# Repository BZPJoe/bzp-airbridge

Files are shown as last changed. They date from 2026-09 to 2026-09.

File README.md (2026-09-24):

# BZP Airbridge

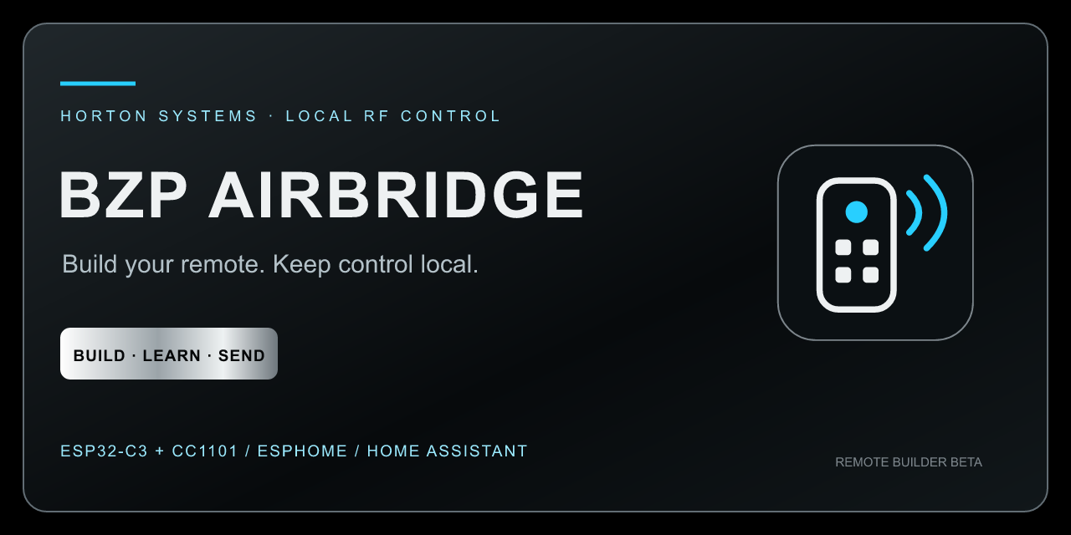
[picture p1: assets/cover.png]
BZP Airbridge — build your remote, keep control local


**Build your remote. Learn its buttons. Keep control local.**

An ESP32-C3 + CC1101 RF bridge with an offline settings page, visual Remote Builder, encrypted ESPHome connectivity, and optional Home Assistant/HomeKit fan control.

**v0.2.0 beta.** Airbar power replay has been confirmed on the project hardware. A captured signal is not proof of appliance compatibility. This is not a universal remote or rolling-code bypass.

## Features
 
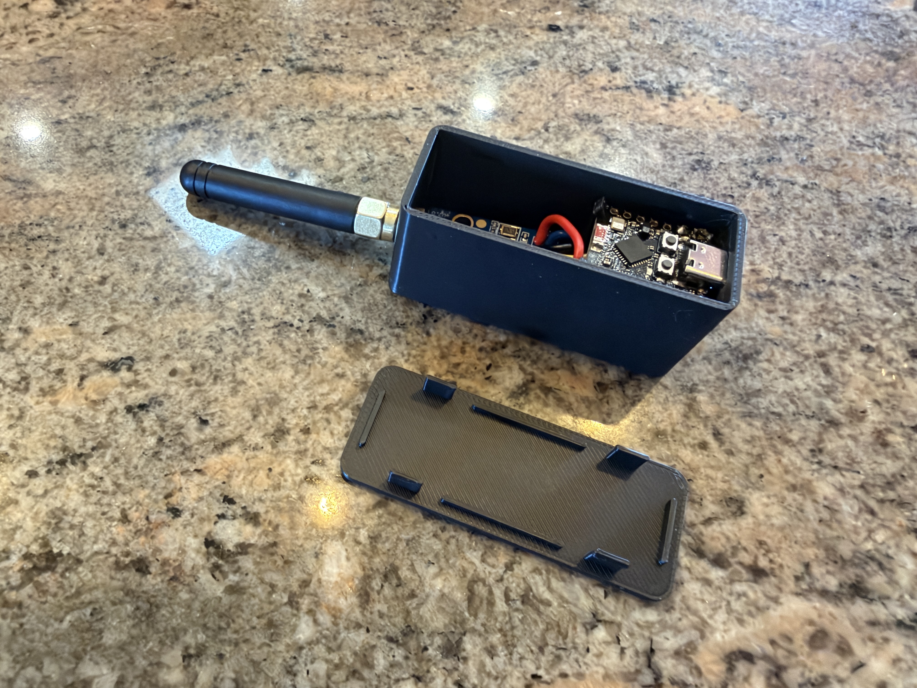
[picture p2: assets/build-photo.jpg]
BZP Airbridge assembled in its printed case, with the removable lid alongside


The actual project build: ESP32-C3 and CC1101 installed in the printed enclosure.

**Print this case:** [Download the case and print profile on MakerWorld](https://makerworld.com/en/models/3271985-bzp-airbridge-esp32-c3-cc1101-controller-case#profileId-3710223).

- Four custom remotes sharing eight custom button slots.
- Name, icon, and position editing before learning individual buttons.
- Animated 20-second listening countdown and explicit save/discard.
- Private JSON backup/import with schema and pulse validation.
- Stable Home Assistant custom-button entities.
- API-key finding aid for locating the existing ESPHome encryption key during Home Assistant setup; the key remains private and is never part of the public repository.
- Home Assistant keeps the last known fan state across Airbridge power loss and reconnects. The settings page provides **Sync fan state** (Off/Low/Medium/High), with the current Home Assistant estimate shown alongside it.
- Existing Vornado power/speed controls and stored captures preserved.
- 2.4 GHz Wi-Fi configuration with rollback, remote reboot, and password-protected ESPHome OTA.
- Horton Systems chrome/cyan styling; all page assets stored on-device.

**Update delivery:** Auto updates and Check for updates remain staged controls. They do not download GitHub releases in this beta. ESPHome OTA works separately.

## Start here

1. [Wire the hardware](docs/WIRING.md) with USB disconnected.
2. [Build and flash](docs/SETUP.md) using your own private credentials.
3. Open http://bzp-airbridge.local or your device’s local IP.
4. [Build and learn remotes](docs/REMOTE-BUILDER.md).
5. [Add Home Assistant and Apple Home](docs/HOME-ASSISTANT.md).

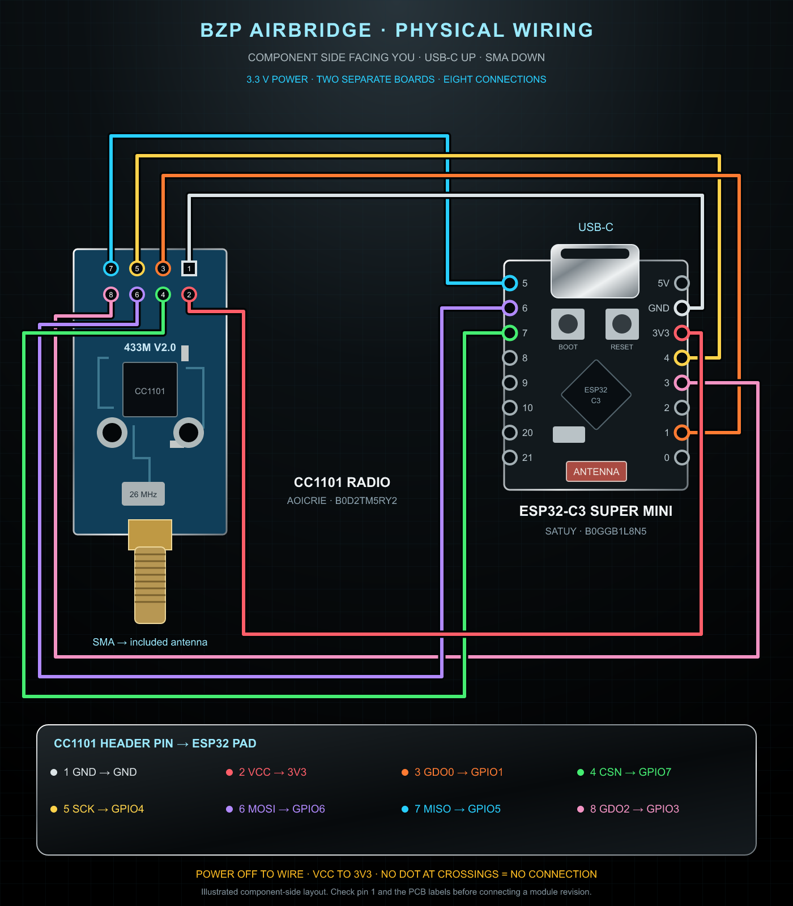
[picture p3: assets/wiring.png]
Physical boards and eight color-coded connections


## Compatibility

Project hardware: ESP32-C3 Super Mini (ASIN B0GGB1L8N5) and AOICRIE CC1101/SMA 433 MHz radio (ASIN B0D2TM5RY2). Board revisions differ: follow signal names and check pin 1.

**Get the parts:** [Below Zero Productions — Gear We Use & Recommend](https://www.belowz.com/gear/). This page contains Amazon affiliate links. As an Amazon Associate I earn from qualifying purchases.

Shipped profile: **433.937 MHz ASK/OOK**, eight-repeat playback. All custom remotes share this profile. Custom capacity: 16–256 alternating pulses, 50–30,000 µs each, 3–500 ms total. Protected legacy slots retain their 512-pulse format. No infrared, Bluetooth, rolling-code, automatic decoding, arbitrary FSK, or multi-frequency support is claimed. Operate only authorized devices and obey local RF rules.

## Home Assistant

The original three buttons retain their names. Eight additional entities are named **Custom button 1–8**. Their identities stay stable when you rename/reorder layout buttons; rename them separately in Home Assistant if desired. Empty slots refuse transmission.

The optional [fan package](examples/home-assistant/bzp_airbridge.yaml) wraps the Airbar controls as a three-speed fan. Its state is estimated, not physical feedback. Its dedicated HomeKit Bridge exports only `fan.bzp_airbridge` as one fan accessory; the Home Assistant bridge service page may itself show no entities. If a bridge was reset/unpaired, remove only its stale BZP Airbridge entry from Apple Home and pair again using the current Home Assistant notice. See [Home Assistant and Apple Home setup](docs/HOME-ASSISTANT.md). Custom remotes do not automatically become fans/lights/covers.

## Development

```sh
python3 -m venv .venv
. .venv/bin/activate
pip install -r requirements.txt
cp firmware/secrets.example.yaml firmware/secrets.yaml
# Replace example credentials before flashing.
python tools/build_ui.py
c++ -std=c++17 tests/test_pulses.cpp -o /tmp/airbridge-pulses && /tmp/airbridge-pulses
c++ -std=c++17 tests/test_builder.cpp -o /tmp/airbridge-builder && /tmp/airbridge-builder
node tests/test_builder.js
esphome compile firmware/airbridge.yaml
```

[Architecture](docs/ARCHITECTURE.md) · [Validation](docs/VALIDATION.md) · [Brand kit](docs/BRAND.md) · [Changelog](CHANGELOG.md) · [Contributing](CONTRIBUTING.md) · [Security](SECURITY.md)

[Settings preview](docs/settings-preview.html) works when served locally and cannot control hardware. Download the [owner-supplied case base and top](hardware/enclosure/user-supplied/README.md). The [earlier generated enclosure](hardware/enclosure/PRINT_AND_ASSEMBLY.md) is retained as a prototype reference; its measurements do not apply to the owner-supplied parts.

[Full settings screenshot](assets/remote-builder-preview.png) · [390 px layout preview](docs/mobile-preview.html)

[MakerWorld description](docs/MAKERWORLD.md) · [Case-parts render](assets/makerworld/case-parts-render.png) · [Software overview](assets/makerworld/software-overview.png)

## Privacy and license

Never publish personal secrets, compiled firmware, raw radio logs, or private remote backups. RF backups can control your devices even without Wi-Fi credentials. Public releases contain source only.

Original code/artwork: [MIT](LICENSE). Horton Systems branding remains its owner's property. See [third-party notices](THIRD_PARTY_NOTICES.md). Independent project, unaffiliated with Vornado, Espressif, Texas Instruments, Apple, or Home Assistant.

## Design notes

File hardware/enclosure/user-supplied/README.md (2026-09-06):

# User-supplied case — September 6, 2026

These are the project owner's supplied case parts, preserved byte-for-byte. Use these files for the current case rather than the earlier generated prototype in the parent folder.

- [Base](Vornado%20Fan%20Controller%20Case.stl): 15,248 triangles; bounding dimensions 60 × 24 × 25.786 model units.
- [Top](Vornado%20Fan%20Controller%20Case%20Top.stl): 4,106 triangles; bounding dimensions 60.7 × 24.7 × 6.986 model units.

STL does not encode units; confirm millimeters and orientation in your slicer. Binary STL structure was checked. No geometry, mounting features, or print supports were added. These files have not been physically fit-tested by this release process. The earlier prototype's assembly dimensions and validation report do not describe these parts.

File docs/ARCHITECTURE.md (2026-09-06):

# Architecture

ESPHome 2026.8.2 supplies Wi-Fi, encrypted native API, OTA, CC1101 state switching, and RMT pulse I/O. Airbridge adds the local UI, validated capture storage, and explicit replay controls.

## Protected Vornado controls

The original three globals retain their identities and 512-pulse capacity. Existing captures survive the builder upgrade. They use ESPHome preferences with a one-minute flash interval; allow 65 seconds after saving before disconnecting power.

## Custom Remote Builder

Four remote names share eight stable button slots. Each button has a label, icon, position, remote assignment, and at most 256 signed pulse durations. The 4,552-byte versioned store is committed as a separate NVS blob (bzp_builder/store_v2). Custom saves acknowledge only after commit; failed imports preserve the prior store. A pending candidate remains separate until Save; Cancel preserves the previously saved command.

GET /airbridge/builder returns layout, status, revision, and private captures. POST accepts raw JSON with Content-Type: application/json and X-Airbridge-Request: builder. Payloads are bounded to 26,000 bytes. Operations: replace, learn, save, cancel, send. HTTP 200 with Accepted means queued, not completed: clients poll until revision changes, then inspect error. Never automatically repeat an uncertain send request.

Input checks cover schema/profile, slot counts, name lengths, integer bounds, pulse count/polarity/duration, and active remote assignments. The device defers mutations to its main loop. Native HTTP body delivery is chunked; URL-encoded form handling is deliberately not used for layouts.

## Radio and integrations

All slots share 433.937 MHz ASK/OOK, eight repeats, zero added gap. Explicit valid sends automatically enable transmission. Learning, pending custom candidates, overlapping sends, and invalid/empty frames block replay. The radio returns to receive after transmission. These are emission checks, not appliance feedback.

Home Assistant sees the original three buttons plus eight stable Custom button entities. A separate optional three-speed fan wrapper maintains an estimate and exposes only that fan through HomeKit. Physical remote use requires resynchronization.

## Security boundary

The no-login HTTP page is for a trusted isolated LAN only. The custom request header is a cross-origin browser defense, not authentication. RF backups contain usable control data. API encryption and OTA passwords do not encrypt the web page. Keep the device off the public Internet and do not publish private backups or deployment binaries.

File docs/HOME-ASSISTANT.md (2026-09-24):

# Home Assistant and Apple Home

## Add the ESPHome device to Home Assistant

Add the Airbridge through Home Assistant's ESPHome integration using its API encryption key. The Airbridge settings page now includes an API-key finding aid to help locate the existing key needed for setup. Treat the discovered key as a credential: use it only for the local ESPHome connection, and never paste it into public issues, screenshots, or GitHub files. The key finder does not replace the ESPHome pairing flow.

Native custom button entities 1–8 keep stable identities; their labels in Remote Builder do not rename Home Assistant entities. Empty slots cannot transmit. Explicit commands automatically enable transmission; learning and overlapping sends still block playback.

## Optional fan wrapper

The [example package](../examples/home-assistant/bzp_airbridge.yaml) is the project's three-speed Airbar wrapper. It is not a universal fan profile. Verify the number of speeds, non-wrapping speed-down behavior, and all three learned commands before using it. Adjust entity IDs to match your installation.

1. Enable packages under `homeassistant: packages: !include_dir_named packages` in your existing configuration, merging rather than duplicating that section.
2. Place the example in `packages/bzp_airbridge.yaml`.
3. Check configuration, then restart Home Assistant.
4. In the Airbridge settings page, use **Sync fan state** to select the fan's actual Off/Low/Medium/High state, then press **Sync fan state**. The Home Assistant estimate on the page confirms the change. The Home Assistant resync selector is also available. A first installation starts Unsynced until this is done.

Power-on from Off normalizes to Low with two speed-down commands before stepping to the target. This assumes a three-speed fan that stops at Low rather than cycling. Every command is serialized. A completed RF replay means the bridge emitted the signal—not that the appliance received it. Fan state is estimated, not physical feedback. After using a physical remote or changing power externally, resync the estimate.

## Power loss and manual sync

Starting with 0.2.2-beta.1, the package retains its last known fan estimate through an Airbridge power loss, Wi-Fi disconnect, or Home Assistant restart. HomeKit can show No Response while the bridge is actually disconnected; control returns automatically with the saved estimate after it reconnects. It does not transmit a command to force the physical fan into that state.

The estimate is stored in Home Assistant's restoring input-select helper. Changes to the physical fan while the bridge is offline can make it inaccurate. Correct it under **Sync fan state** in the device settings page: choose Off, Low, Medium, or High and press the sync button. This updates Home Assistant and HomeKit without transmitting RF. It also stops any pending fan-control sequence so it cannot overwrite your correction.

Upgrade both the firmware and the example Home Assistant package. For an existing package installation, validate configuration and reload automations after replacing the package. Remove the old `bzp_airbridge_observer_disconnect` automation if you merged the update manually; leaving it active still clears state on disconnect. Keep the existing helper and entity IDs so their stored state and Apple Home identity are preserved.

Received commands and completed web-page replays update the estimate when observed in sequence. Reconnect snapshots and sequence gaps retain the prior estimate instead of guessing what happened while offline. Passive handheld recognition depends on the radio receiving the remote reliably; it is not physical fan feedback. Failed/interrupted control sequences may still require manual sync.

## Publish the fan to Apple Home

Home Assistant and Apple Home are two separate steps. The ESPHome device appearing in Home Assistant does not automatically add an accessory to Apple Home.

The dedicated HomeKit Bridge section in the example exports **only `fan.bzp_airbridge`**, named **BZP Airbridge**, on port **21268**. When paired, Apple Home should show a fan accessory with on/off and three-speed control. Do not add the power switch and speed selector separately; the fan entity is the combined accessory.

1. Confirm `fan.bzp_airbridge` is available (not `unavailable`). On first setup, or if the estimate is Unsynced after an interrupted command, use **Sync fan state** to enter the fan's actual state. Ordinary reconnects preserve the estimate.
2. Check Home Assistant configuration, then restart Home Assistant or run the HomeKit reload action to apply YAML changes.
3. In Home Assistant, open **Settings → Devices & services → HomeKit Bridge**. Find **BZP Airbridge** and its pairing card/code in Notifications.
4. In Apple Home, choose **Add Accessory**, then scan the QR code or use **More Options / Don't Have a Code?** and enter the current code. Keep the iPhone and Home Assistant on the same local network so discovery can work.
5. Look for the **BZP Airbridge** fan accessory in Apple Home. The Home Assistant HomeKit *service device* page may say “This device has no entities”; that page represents the bridge service and is not the accessory list.

### If the bridge is already in Apple Home but has no fan

Confirm `fan.bzp_airbridge` is available and the HomeKit filter includes that entity. If the bridge was forcefully unpaired or reset in Home Assistant, Apple Home may still show its old saved bridge entry even though it no longer matches the active pairing.

Remove **only the stale BZP Airbridge bridge** from Apple Home, then add it again using the current BZP Airbridge pairing notice in Home Assistant Notifications. Unpairing applies to this HomeKit bridge; it does not affect other Home Assistant HomeKit bridges. After re-pairing, check the Home app's bridge/accessory details and its room for the fan tile.

If the bridge cannot be discovered, verify both devices are on the same LAN and the router allows local multicast/mDNS discovery; guest Wi-Fi, client isolation, VLANs, or multicast filtering can prevent discovery. Do not delete unrelated HomeKit bridges.

Home Assistant uses entity IDs as HomeKit accessory identity, so keep `fan.bzp_airbridge` stable if you want to preserve its Home app settings. HomeKit changes may take a moment to appear after a reload.

## Custom commands

Custom buttons can be used in automations with `button.press`. They do not automatically map to fan percentages or Apple Home accessories. Build a separate suitable wrapper for each appliance; never apply this fan state model to a different remote without testing.

Keep API keys, Wi-Fi credentials, pairing codes, and household configuration private. Do not put live setup codes or personal network details in this repository.

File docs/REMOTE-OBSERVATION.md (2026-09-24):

# Physical remote observation (0.2.1 beta)

The receiver now compares incoming frames with the three saved fan commands outside learning mode. Matching uses the full signed pulse sequence with 25% + 80 microseconds tolerance, excluding the trailing receiver idle gap. Ambiguous matches are rejected. Repeated copies of the same command within 350 ms of the preceding copy count once. Holding a button is treated as one press until a 350 ms gap; rapid same-button presses may merge. This conservative behavior needs validation with the actual remote.

The diagnostic Observed command sensor reports sequence:source:slot. Source is rx (physical remote) or tx (completed bridge replay); slots 0/1/2 are power/up/down. Starting in 0.2.2, source sync means an explicit settings-page correction; values 0/1/2/3 mean Off/Low/Medium/High. Sync never transmits RF. Background listening never retransmits. Own transmissions and the first 350 ms afterward are excluded. Commands during learning, pending capture review, transmission or radio/Wi-Fi downtime can be missed.

Home Assistant's observer automation updates the existing estimate. The fan-control script already accounts for its own sends, so the automation ignores those tx reports. Direct web/button sends are counted. A physical command during a fan-control sequence stops that sequence and marks the estimate Unsynced. Since 0.2.2, disconnects and sequence gaps retain the last known estimate; reconnect snapshots are ignored. The settings-page **Sync fan state** control and the Home Assistant resync selector can correct an inaccurate estimate.

This is command observation, not appliance feedback. The three-speed model assumes bounded speed steps, speed commands do nothing while off, and power-on resumes the remembered speed. If your fan behaves differently, change the model rather than treating this estimate as fact. Fan-panel changes and missed RF packets remain invisible. Start by setting the resync selector to the actual state, then test power, individual speed presses, rapid presses and held buttons with the physical fan in view.

Recognition has synthetic tests; physical RF acceptance still requires a real remote test after installation. Custom Remote Builder buttons are not assigned fan-state semantics.

## Receive-path diagnostics

`Inspect remote reception` opens a 60-second diagnostic window. It logs saved
frames, raw callback counts and up to six received samples, without changing
saved captures. Keep diagnostic logs private: learned RF codes should not be
published with the project.

`Test receive line` is specific to this project's GDO2-to-GPIO3 wiring. It
temporarily drives GDO2 low/high twelve times, reads GPIO3, then restores the
original radio output configuration. It does not enter transmit mode. Learning
and observation are suppressed during the test. Twelve successful low and high
reads plus a receiver callback verify the digital receive path, not RF reception.

Raw mode disables packet synchronization. In the dual-pin configuration GDO0
is high-impedance while receiving, since the ESP32 RMT transmit pin remains an
output; GDO2 supplies received data independently. GDO0 is automatically the
radio's data input in asynchronous transmit mode.

The receiver bandwidth setter also applies the matching analog settings from
[TI DN022 section 3.2](https://www.ti.com/lit/an/swra215e/swra215e.pdf).
At 203.125 kHz these are FREND1=B6, TEST2=81, TEST1=35 and FIFOTHR bit 6=1.
The OOK AGC starting point is 03/00/91, with frequency compensation disabled.
These are documented starting settings, not a substitute for over-the-air
acceptance testing at the installation location. The timed reception diagnostic
also reports min/max RSSI and sampled GPIO3 levels once per second.

`Scan remote reception` is an 18-second receive-only diagnostic: nine two-second
steps from 433.137 to 434.737 MHz using a 650 kHz receive bandwidth and 355 kHz IF.
Record an untouched-remote baseline first, then repeat with the physical remote.
The scan blocks replay and learning, does not update the fan estimate, and restores
this firmware's normal 433.937 MHz / 203 kHz / 153 kHz IF profile automatically.
No scan setting or received sample is saved to flash. Restarting also restores
the normal configured profile. Background RF energy is not proof of remote reception.
# Temporary USB reception comparisons

These diagnostics are experimental, not a confirmed passive-reception fix.
`Original reception test` restores the published learning-era modem and analog
register values for five minutes, while keeping the shared TX-connected GDO0
high impedance to avoid output contention. Frequency and saved commands are
preserved. All incoming callbacks are counted before the application's validity
checks or observer matching. The normal settings are restored automatically.
This is a controlled comparison, not an exact rollback of the entire firmware.
`USB quiet reception test` records five seconds with Wi-Fi enabled, disables
Wi-Fi for 30 seconds while USB logging continues, then reenables Wi-Fi.
`Reference reception test` snapshots the normal radio configuration, reads
the chip's reset defaults and applies an OOK 270 kHz receive profile adapted
from the [Flipper CC1101 configurations](https://github.com/flipperdevices/flipperzero-firmware/blob/dev/lib/subghz/devices/cc1101_configs.c).
It retains the configured frequency and uses GDO2 for reception. After 90 seconds
it automatically restores the normal configuration. Both tests block replay and
learning, leave saved captures intact, and do not update estimated fan state.
A reboot also restores the normal configured profile. Verify actual fan state
before manually resynchronizing Home Assistant after testing.

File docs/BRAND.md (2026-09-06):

# Brand kit

**BZP Airbridge** · Build your remote. Keep control local.

Horton Systems header branding, black/steel panels, chrome buttons, and cyan accents match the owner's UniFi Sentinel style. The new geometric mark combines a remote with radio arcs, not generated fan blades.

| Token | Color |
|---|---|
| Black / panel | #000000 / #0B1013 |
| Steel / chrome | #7C858B / #EEF1F2 |
| Cyan / pale cyan | #28CFFF / #9BEAFF |
| Green / amber | #45ED72 / #FFBD22 |

Editable assets: icon.svg, wordmark.svg, cover.svg, wiring.svg. PNG counterparts are portable exports. Cover dimensions: 1280×640. Preserve clear space and proportions.

python tools/build_ui.py embeds the current assets/UI. python tools/render_assets.py requires resvg-py and produces PNGs. Horton Systems branding remains its owner's property.

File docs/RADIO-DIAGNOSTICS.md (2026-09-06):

# Radio diagnostics

The local `cc1101` component is based on ESPHome 2026.8.2's component, with read-only register diagnostics added to its public interface. Upstream: https://github.com/esphome/esphome/tree/2026.8.2/esphome/components/cc1101 (ESPHome C++ runtime, GPLv3; see the included upstream license).

`Read radio diagnostics` is a diagnostic button exposed through ESPHome. Pressing it reads PARTNUM, VERSION, MARCSTATE, PKTCTRL0 and FSCAL1 and logs the saved Power pulse sequence without altering it. Run it when the bridge is idle.

Replay now enters TX before handing pulses to the transmitter. If MARCSTATE is not TX (`0x13`), it aborts replay and reports an error. After pulse completion, it checks RX (`0x0D`). Successful state transitions and pulse completion do not prove RF reception by the fan.

Stored frame IDs and serialization are unchanged. Raw frame timings can identify a remote's command; keep diagnostic logs private.

Live diagnostic finding: the saved Power frame contains 50 signed durations and ends in a -12000 us receiver idle period. The former extra 12 ms repeat wait doubled this separation. Replay now preserves the captured trailing gap and adds no extra repeat delay. Hardware fan response remains the final acceptance test.

Further live readback: PA=00,40; FREND0=11; MDMCFG2=32; IOCFG0=0D; FREQ=10B09C. GPIO1 output selection is 0x33 (RMT source 51), with GPIO1 output enabled. This rules out a zeroed OOK power table and a detached RMT route at the time of reading, but does not measure radiated RF.

The AIRBAR FCC grant lists 433.937 MHz: https://fccid.io/WOT-AIRBAR . The radio remains at that carrier. An eight-repeat playback trial replaces the former three repeats to test the longer burst envelope observed from the original remote. This is experimental until the user confirms fan response; the stored frame is unchanged.

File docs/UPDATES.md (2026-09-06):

# Staged software updates

The settings page and Home Assistant expose:

- Auto updates: a persistent preference, off by default.
- Check for updates: a manual action.
- Update status and Firmware version: device-reported text.

There is no release URL, GitHub request, download, or automatic installation in
this build. The manual check reports that a release source is not configured.
When the preference is enabled, a six-hour timer calls that same staged check.
It cannot claim the firmware is up to date without an actual release check.

When GitHub releases are ready, connect the shared check_updates hook to the
release mechanism, including version comparison, artifact validation, installation
status, failure handling, and rollback testing. Honor the stored Auto updates
preference for automatic installation. Manual checks must not automatically install
when that preference is off.

Existing password-protected ESPHome OTA remains available for development.
Before publishing public update binaries, establish a provisioning scheme that
keeps each user's Wi-Fi/API/OTA credentials out of the release artifact.

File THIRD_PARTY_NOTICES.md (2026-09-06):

# Third-party notices

- ESPHome 2026.8.2: https://github.com/esphome/esphome/tree/2026.8.2 — C++ runtime GPLv3; Python and other portions MIT. Vendored firmware/components/cc1101 comes from that release with local diagnostic additions and retains its upstream license. See licenses/ESPHome-LICENSE.txt. The root MIT license does not replace upstream licensing; combined firmware is subject to upstream runtime terms.
- Horton Systems logo belongs to its owner, included with project-owner authorization; not relicensed by MIT.
- Settings styling follows the owner's UniFi Sentinel project: https://github.com/BZPJoe/unifi-sentinel .
- Platform/manufacturer names identify compatibility targets, not endorsement.
- Original Airbridge SVG artwork is licensed with the project. Board drawings are illustrations, not certified mechanical drawings.

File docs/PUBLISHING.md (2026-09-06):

# Publishing

Public project: https://github.com/BZPJoe/bzp-airbridge

Build a sanitized source archive with `python tools/package.py /tmp/bzp-airbridge-source.zip`. Publish from that archive, never by blindly adding your deployment folder. The packager restricts public directories/extensions and rejects known local secret values. Review its output too: automated scanning is not a complete security guarantee.

Use a beta/prerelease label until physical custom-remote replay, long-term Wi-Fi reliability, speed behavior, and enclosure fit have been verified. The validation report separates software checks from appliance tests.

The GitHub workflow compiles with dummy credentials and does not publish firmware binaries. Build deployment images locally. Never attach real Wi-Fi/API/OTA credentials, raw captures, logs, private backups, or deployment binaries to a public release.

Original code is MIT; vendored ESPHome C++ retains GPLv3. See THIRD_PARTY_NOTICES.md and the included upstream license. Horton Systems marks remain their owner's property.

Brand sources and PNGs are in assets/. The cover can be used as the repository social preview.

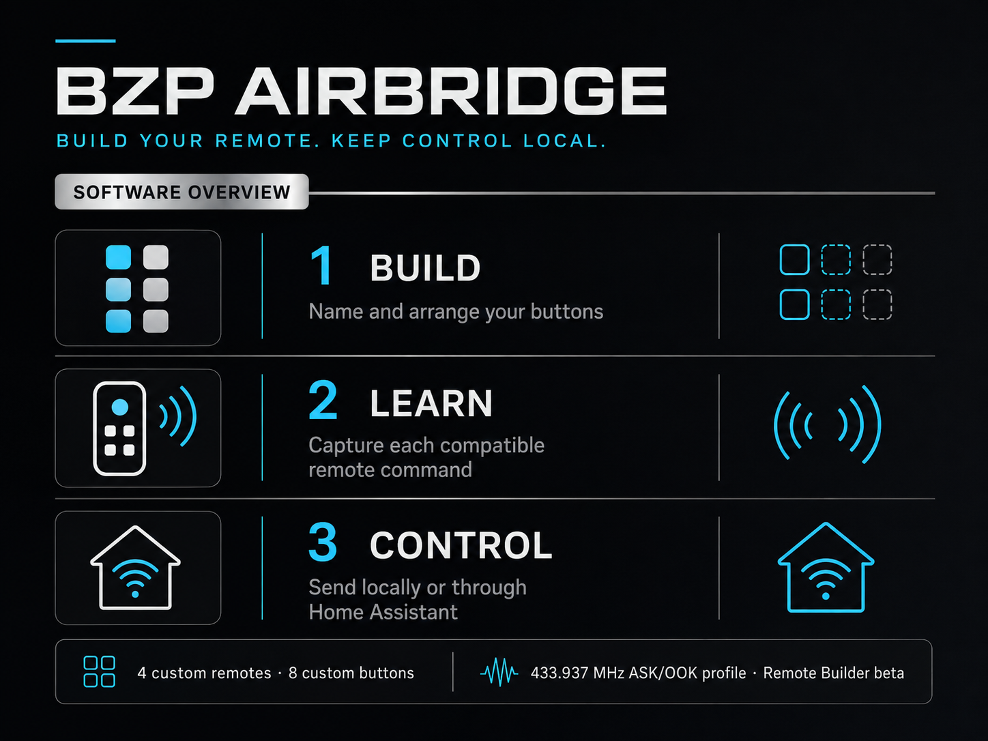
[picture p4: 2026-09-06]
assets/makerworld/software-overview.png

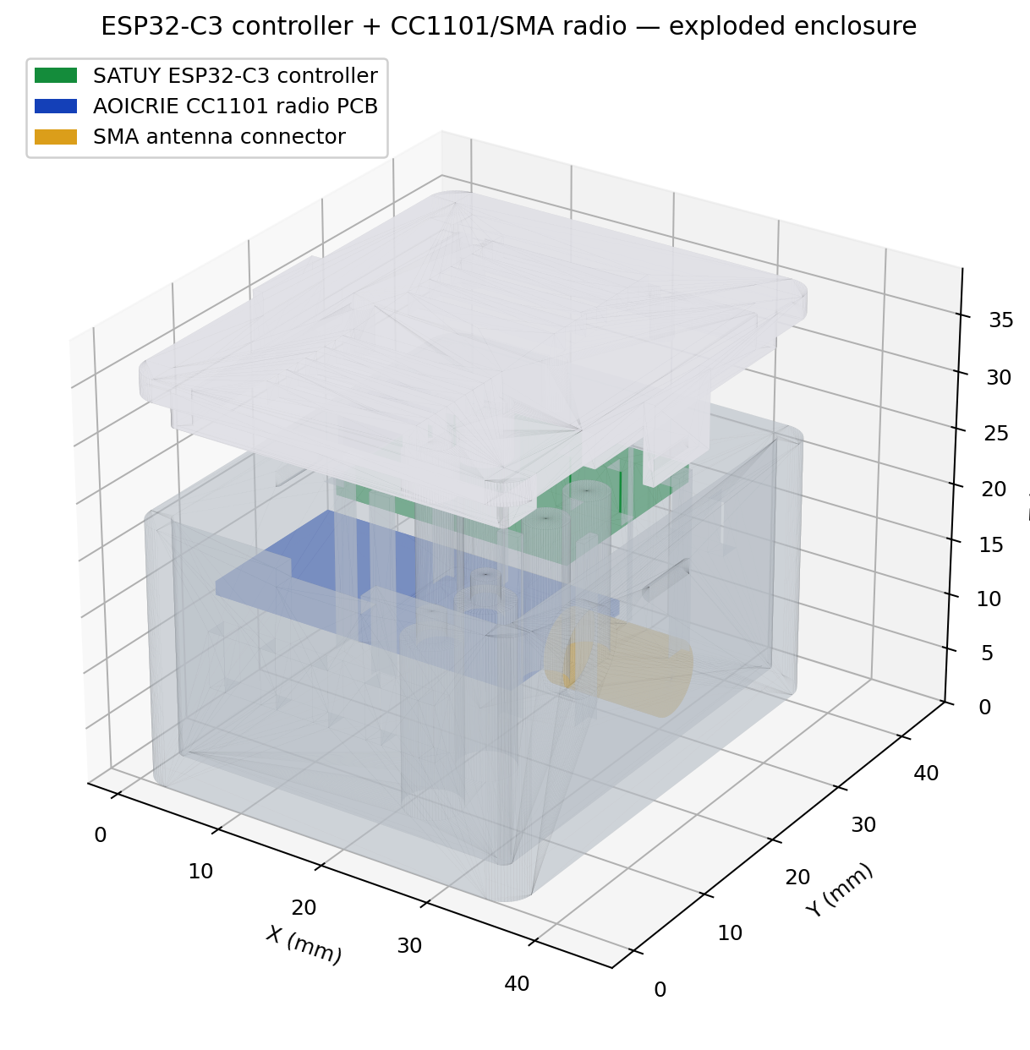
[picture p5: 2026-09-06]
hardware/enclosure/vornado_rf_enclosure_preview.png

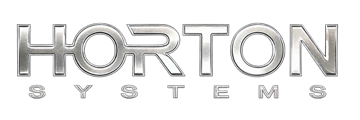
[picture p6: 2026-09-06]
assets/horton-systems.png

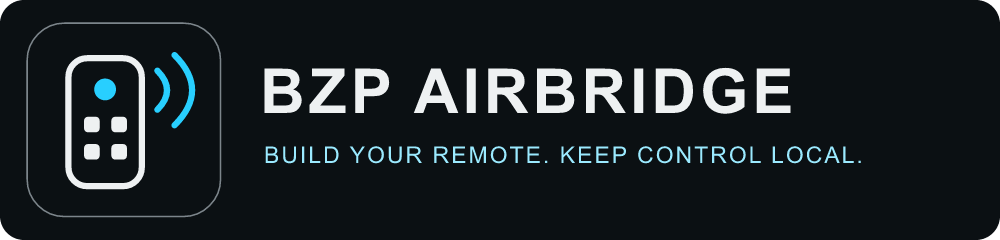
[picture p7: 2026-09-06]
assets/wordmark.png

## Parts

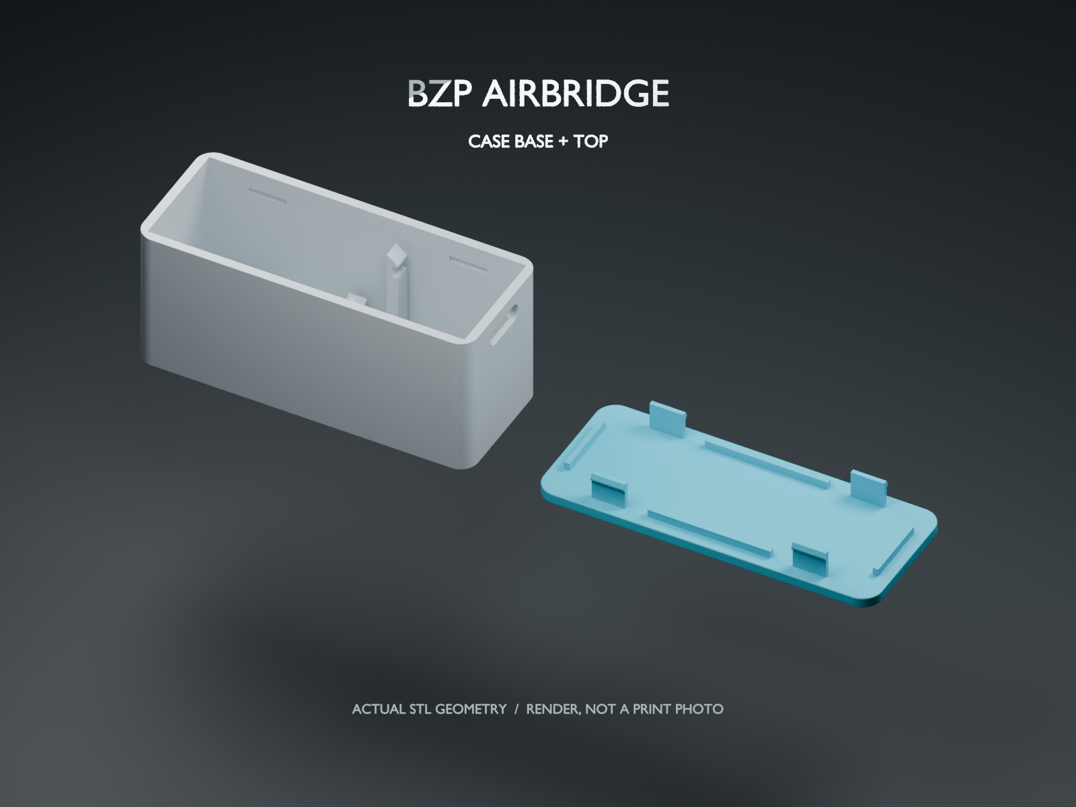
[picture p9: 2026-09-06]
assets/makerworld/case-parts-render.png

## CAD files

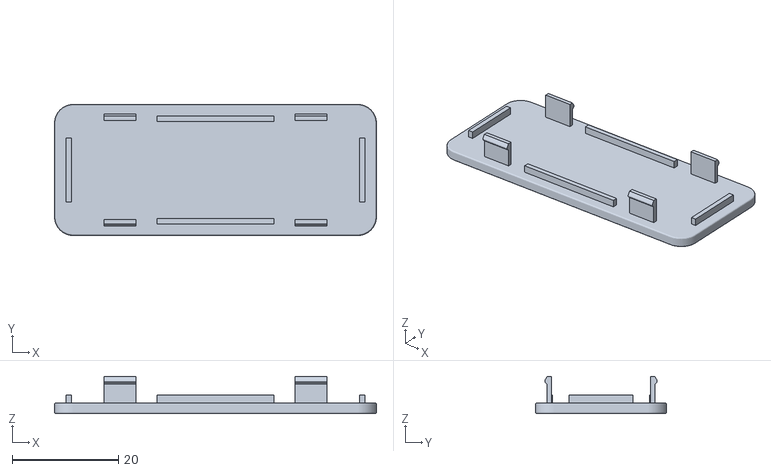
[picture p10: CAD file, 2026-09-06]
hardware/enclosure/user-supplied/Vornado Fan Controller Case Top.stl
60.7 x 24.7 x 6.99

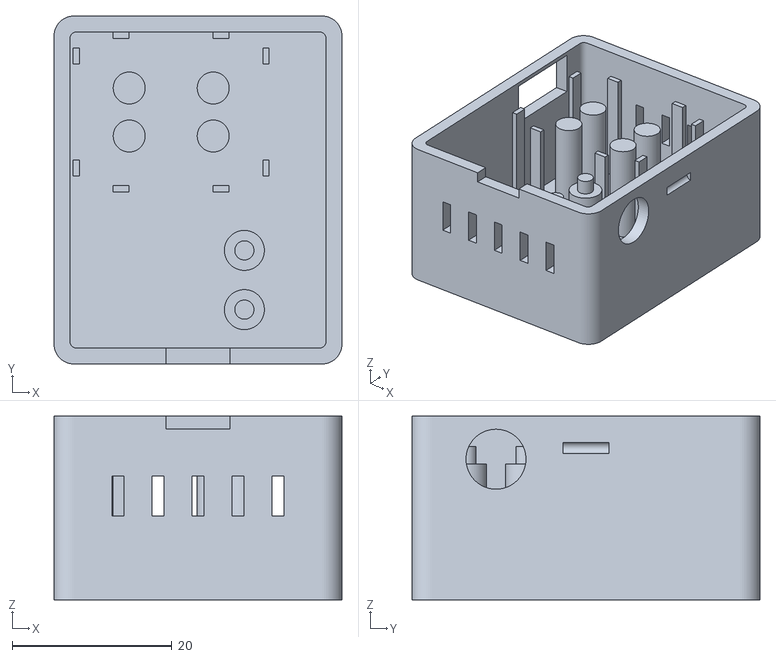
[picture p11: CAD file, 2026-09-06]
hardware/enclosure/vornado_rf_enclosure_base.stl
36.0 x 43.5 x 23.0

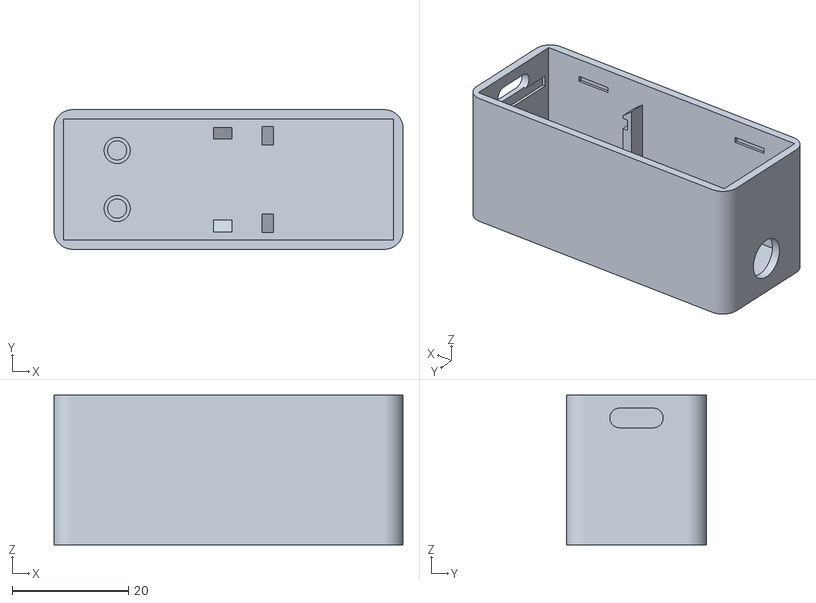
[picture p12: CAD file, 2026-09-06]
hardware/enclosure/user-supplied/Vornado Fan Controller Case.stl
60.0 x 24.0 x 25.8

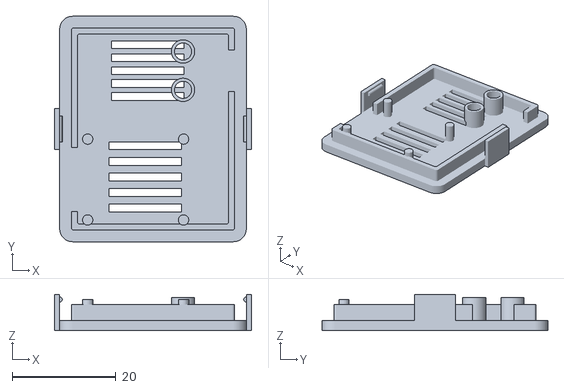
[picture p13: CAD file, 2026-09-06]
hardware/enclosure/vornado_rf_enclosure_lid.stl
38.0 x 43.5 x 7.00

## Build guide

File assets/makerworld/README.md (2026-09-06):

# MakerWorld supporting images

- case-parts-render.png: 1600 × 1200 render of the supplied base and top. Clearly labeled as a render, not a print photo. Source STL files remain unchanged. Blender's importer discards degenerate/duplicate triangles for display only.
- software-overview.png: AI-generated supporting infographic using the built-in image-generation tool, reviewed for wording and branding. It is not a hardware or print photograph.
- wiring.png: existing physical-board wiring illustration, copied unchanged.

MakerWorld's upload form requests real printed-model photos for covers. Use an actual print photo for the cover; these graphics are supporting material. Confirm the selected license before publishing the draft; the current MakerWorld license selections may differ from the GitHub project's licensing. No license selections were changed by this task.

## Image-generation prompt

Create a polished 4:3 landscape supporting infographic for a MakerWorld listing for BZP Airbridge. Use the existing cover only for established brand styling: black and charcoal, restrained cyan #28CFFF, silver/chrome, clean typography and a simple remote-with-radio-arcs icon. This is a SOFTWARE OVERVIEW graphic, not a product photograph and not a claim about physical case appearance. Do not draw any enclosure, circuit boards, fan, fake screen, cables, or invented hardware. Use three clearly separated steps with simple button-grid, remote/radio, and home icons. Exact text: BZP AIRBRIDGE; BUILD YOUR REMOTE. KEEP CONTROL LOCAL.; 1 BUILD; Name and arrange your buttons; 2 LEARN; Capture each compatible remote command; 3 CONTROL; Send locally or through Home Assistant; 4 custom remotes · 8 custom buttons; 433.937 MHz ASK/OOK profile · Remote Builder beta; SOFTWARE OVERVIEW. No URLs, QR codes, external-brand badges, excessive glow, or decorative circuitry.

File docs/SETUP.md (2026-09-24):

# Setup and recovery

Disconnect USB before wiring. CC1101 VCC goes to **3V3, never 5V**. Attach the correct SMA antenna before transmitting. Keep the ESP32 antenna clear of the radio board, metal, and bundled wires.

Use Python 3.12 and the pinned requirements. Copy firmware/secrets.example.yaml to firmware/secrets.yaml and replace all values with your own. Keep this file out of version control. ESP32-C3 requires 2.4 GHz Wi-Fi, not 5 GHz.

```sh
python tools/build_ui.py
esphome run firmware/airbridge.yaml
# Subsequent wireless update:
esphome upload firmware/airbridge.yaml --device bzp-airbridge.local
```

First installation uses USB. Wait for upload success and reconnect; slow Wi-Fi can take several minutes. Never distribute binaries compiled with personal credentials.

Open http://bzp-airbridge.local or the router-assigned local IP. The HTTP page intentionally has no sign-in: trusted LAN only, no internet port forwarding. Native ESPHome API encryption is separate from HTTP.

For Home Assistant setup, the settings page includes an API-key finding aid to help locate the existing ESPHome API encryption key. Use that key for the ESPHome integration only. It is a credential: never publish it in screenshots, support posts, or GitHub. The finder does not make the settings page internet-safe; keep the device on a trusted LAN.

To reveal the key, hold BOOT for at least two seconds with the device already running, release it, and click **Reveal encryption key** within 30 seconds. Each press unlocks one reveal; the page clears the key after 30 seconds or when hidden. Do not hold BOOT during power-on/reset for this operation.

With firmware 0.2.2-beta.1 and the updated [Home Assistant package](HOME-ASSISTANT.md), the fan resumes its last known estimate when Airbridge reconnects after losing power. Under **Sync fan state**, choose the actual Off/Low/Medium/High state and press the sync button if correction is needed. Check the displayed Home Assistant estimate for confirmation. Sync does not transmit RF.

The Wi-Fi form tests the new network before saving, with a 45-second rollback. Credentials are POSTed, not placed in URLs. HTTP still requires a trusted network.

## Recovery and preservation

Identify BOOT and RESET/RST using PCB markings. Holding BOOT while tapping RESET then releasing BOOT permits USB recovery. A normal reset does not erase stored captures.

v0.2 keeps the original power/up/down globals and names; custom remotes use separate versioned NVS storage. Do not erase flash or change partition layouts when upgrading. Export custom backups first.

Legacy captures retain the delayed preference write: wait 65 seconds after saving before removing power. Custom layout/capture success is reported after NVS commit. Custom backups exclude the original Vornado captures.

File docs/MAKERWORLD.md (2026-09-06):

# BZP Airbridge ESP32-C3 + CC1101 Controller Case

A compact, two-piece enclosure for **BZP Airbridge**, a local RF remote-control bridge built around an ESP32-C3 Super Mini and a CC1101 radio module with an SMA antenna.

The project started as a way to bring a Vornado fan into Home Assistant. The Remote Builder beta also lets you create your own button layouts, then learn each button from a compatible RF remote.

## What is included

- Case base and removable top.
- The MakerWorld print profile/3MF supplied with this listing.
- Open-source firmware, wiring illustration, setup instructions, and Home Assistant example on GitHub.

## What Airbridge can do

- Build up to four custom remotes sharing eight custom buttons.
- Name, arrange, and assign icons to buttons before learning them.
- Learn individual commands with a listening animation and save/discard controls.
- Back up and restore custom remote layouts and learned commands privately.
- Send commands from the local settings page or Home Assistant.
- Keep the original Vornado power and speed controls separate from custom remotes.

## Electronics and parts

The case is intended for the specific boards used in this project:

- SATUY ESP32-C3 Super Mini — ASIN B0GGB1L8N5. One board is needed; the linked listing is a multipack.
- AOICRIE CC1101 radio module with SMA antenna — ASIN B0D2TM5RY2. One module is needed; the linked listing is a multipack.
- Suitable insulated hookup wire and USB-C power cable.

**Parts used in the project:** [Below Zero Productions — Gear We Use & Recommend](https://www.belowz.com/gear/)

The parts page contains Amazon affiliate links. As an Amazon Associate I earn from qualifying purchases.

**Firmware, wiring, setup, and source:** [BZP Airbridge on GitHub](https://github.com/BZPJoe/bzp-airbridge)

## Before printing and assembly

Review the supplied 3MF profile and slicer preview for your printer and material. Board revisions can differ, so check connector access and fit before final assembly. Disconnect USB while wiring. Power the CC1101 from 3.3 V, not 5 V, and keep wiring clear of the ESP32 antenna. Attach the SMA antenna before transmitting.

## Compatibility notes

This is not a universal remote. The current firmware uses a fixed **433.937 MHz ASK/OOK** profile. Other frequencies, infrared, Bluetooth remotes, and rolling-code systems are not supported by this profile. New remote compatibility requires testing. The ESP32-C3 uses 2.4 GHz Wi-Fi.

Home Assistant fan state is estimated from commands, not reported by the fan. GitHub-based automatic firmware installation is not implemented in this beta; ESPHome OTA is available separately.

This is an independent DIY project, not affiliated with or endorsed by Vornado.

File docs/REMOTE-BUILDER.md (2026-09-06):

# Remote Builder

1. Select an empty remote in **Build your remote** and save its name.
2. **Add button**: choose label, icon, and position. Build the whole layout first.
3. Select **Learn** on a button. The animated receiver and countdown mean it is listening; press that key on the original remote.
4. **Command received** is only a candidate. Select **Save learned command** or **Discard capture**.
5. Select **Send** and observe the appliance. A completed replay is not an acknowledgement from the appliance.

Capacity is four custom remotes and eight custom buttons total. Custom captures support 16–256 valid alternating pulses. Timeout or discard preserves the previously learned command. Unsupported/noisy signals can time out.

## Organize

Edit changes label, icon, and position without changing slot identity. Delete requires confirmation and removes that custom button and capture. Original Vornado controls stay separate.

Names are limited to 32 UTF-8 bytes (emoji can use several bytes). User labels render as text, not HTML. Buttons must belong to a named remote.

## Private backups

Export downloads airbridge-private-remotes.json: remote names, slot layout, and custom pulse captures. It contains no network/API credentials and no legacy captures, but it is still private RF control data.

Import validates schema, profile, capacities, and pulse timings before replacing all custom remotes. It asks for confirmation, never transmits automatically, and rejects malformed data. Save/discard an active capture before importing or editing layouts. Export a backup before deletion.

The fixed radio-profile identifier is intentional. Changing private firmware frequency also requires updating this identifier and its validators; automatic frequency selection is not implemented.

## Home Assistant

Custom slots appear as Custom button 1–8. Default entity IDs generally look like button.bzp_airbridge_custom_button_1; verify your actual IDs. Layout renaming does not rename HA entities. Rename in HA if desired.

Arbitrary layouts are not automatically converted to fan/light/cover entities. The Airbar fan example is a separate profile with explicitly estimated state. Avoid simultaneous commands from original remote, web controls, and HA; there is no physical-state feedback.

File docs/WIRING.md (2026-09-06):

# Wiring BZP Airbridge

Disconnect USB while wiring. Attach the included SMA antenna before transmitting.

The illustration shows component-side board outlines: ESP32 USB-C at the top,
CC1101 SMA at the bottom. ESP32 pad positions follow the Super Mini photo.
The radio's two-row header follows the matching E07-M1101D-SMA component-side
drawing: upper row left-to-right 7, 5, 3, 1; lower row 8, 6, 4, 2.
Pin 1 is the square GND pad. Confirm the marking on your radio revision.
Wire crossings without a terminal dot are not electrical junctions.

| ESP32-C3 label | CC1101 signal | Role |
|---|---|---|
| 3V3 | VCC | 3.3 V supply |
| GND | GND | Shared ground |
| GPIO4 | SCK / SCLK | SPI clock |
| GPIO5 | SO / MISO | Radio → controller |
| GPIO6 | SI / MOSI | Controller → radio |
| GPIO7 | CSN / CS | SPI chip select |
| GPIO1 | GDO0 | Raw transmit pulses |
| GPIO3 | GDO2 | Raw receive pulses |

This uses separate receive and transmit GPIOs. GDO0 belongs to the transmitter component and GDO2 belongs to the receiver component. Do not also assign GDO0 to the CC1101 configuration in this dual-pin setup.

GPIO2, GPIO8, and GPIO9 are avoided for this wiring. GPIO18/19 are left for native USB. Connect by board labels, not by a generic drawing's physical pin order. CC1101 board revisions can rotate or mirror their 2×4 headers.

Keep wires short. Power the assembly through the ESP32's USB-C connector. Use the existing case's downward-facing header clearance; permanent locating posts and retention pads are part of the enclosure. No sacrificial supports are included.

Reference: https://esphome.io/components/cc1101/#integration-with-remote-receivertransmitter

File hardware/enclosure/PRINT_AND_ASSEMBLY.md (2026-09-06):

# ESP32-C3 + AOICRIE CC1101 snap-fit enclosure

**Earlier generated prototype.** For the current owner-supplied case files, see [base and top](user-supplied/README.md). The instructions and measurements below apply only to this older design.

This enclosure is for two separate boards:

- **Controller:** SATUY ESP32-C3 Super Mini, Amazon ASIN **B0GGB1L8N5**
- **Radio/antenna assembly:** AOICRIE 433 MHz CC1101 blue PCB with gold SMA connector and the supplied black antenna, Amazon ASIN **B0D2TM5RY2**

The case body is 36.0 × 43.5 × 25.0 mm when closed, excluding the exposed SMA connector and screw-on antenna. The two low-profile side snap arms make the maximum width 38.0 mm. It uses no enclosure screws and no board screws.

## Hardware dimensions used

| Part | Design envelope |
|---|---|
| SATUY ESP32-C3 PCB | 22.5 × 18.0 mm; USB-C centered on the 18 mm end; two 8-pin rows at 2.54 mm pitch |
| AOICRIE/CC1101 radio PCB | 28.0 × 15.0 × 1.2 mm; 2×4 header on one end; SMA centered on the opposite end |
| CC1101 mounting holes | 3.0 mm diameter; hole centerline 10.0 mm from the SMA-side PCB edge |
| SMA connector | 6.2 mm diameter × 9.6 mm long beyond the PCB |
| Supplied black antenna | approximately 50 mm long × 7 mm diameter |

The AOICRIE Amazon dimension graphic repeats “28 mm” on both PCB axes, but its photographed board is rectangular. The official EBYTE mechanical drawing for the visually matching E07-M1101D-SMA layout gives the consistent dimensions: **28 × 15 mm**, with the same SMA connector, 2×4 header, hole pattern, and pin arrangement. Those dimensions—not 28 × 28 mm—were used here.

## Print settings

- Print the base upright with the open side facing up.
- Print the lid exactly as supplied: its smooth outside face goes on the bed.
- 0.4 mm nozzle, 0.20 mm layers, three walls, and 15–25% infill are suitable.
- PETG is preferred for the repeated-flex snap arms; PLA should also work if the lid is not removed frequently.
- **Turn slicer-generated supports off.** Every feature is oriented to print without support material. A brim is optional.
- The lid has 0.25 mm skirt clearance per side and two flexible snap arms. Do not scale only one part unless a test print shows your printer needs compensation.

## Assembly

1. Wire and test the electronics before putting them in the enclosure. Both boards use 3.3 V logic; do not feed the CC1101 from 5 V.
2. The enclosure provides 15 mm below each PCB for downward-facing header pins and female Dupont housings. On the ESP32-C3, solder the supplied headers with the long pins facing down, or solder short insulated wires directly to the board.
3. Connect the inter-board wires before seating the boards. Route them underneath and through the open center channel, keeping the bundle away from the ESP32's onboard antenna end.
4. Insert the CC1101's gold SMA connector through the round opening. Lower its two 3 mm mounting holes onto the locating pins. Its 2×4 electrical header faces the opposite wall. No screws are used.
5. Insert the ESP32-C3's USB-C connector through the rectangular opening and lower the PCB between its locating guides. This board has no mounting holes, so the guides—not screws—keep it positioned.
6. Screw the supplied black antenna onto the SMA connector outside the case, finger-tight only.
7. Align the lid and press both long sides evenly until the two exterior latches click into their wall pockets. To remove it, flex one snap arm slightly outward while lifting at the shallow front-edge notch, then release the other side.

Do not force a board that differs visibly from the specified products. Clone “ESP32-C3 Super Mini” and CC1101 boards can use different PCB outlines or connector positions. The included parametric source keeps the important dimensions near the top of the file if a measured adjustment is needed.

## Included files

- `vornado_rf_enclosure_base.stl` — print-ready base
- `vornado_rf_enclosure_lid.stl` — print-ready removable lid
- `vornado_rf_enclosure_source.py` — editable parametric CAD source
- `vornado_rf_enclosure_preview.png` — exploded fit reference
- `mesh_validation.txt` — closed-mesh and interference-check report

To regenerate the STLs from the source, install Python packages `numpy`, `trimesh`, `manifold3d`, and `matplotlib`, then run:

```text
python3 vornado_rf_enclosure_source.py --output-dir .
```

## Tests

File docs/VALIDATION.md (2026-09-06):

# Validation — Remote Builder beta

Built with ESPHome 2026.8.2 for ESP32-C3, ESP-IDF, 4 MB flash. Final build: 1,113,576 bytes (60.7% of app partition); static RAM 131,262 bytes (40.9%). Compiler success is not an appliance compatibility test.

| Check | Result |
|---|---|
| ESPHome configuration, generated C++, compile/link | Pass |
| Legacy pulse validation/storage native tests | Pass |
| Custom model validation, corrupted data and bounds | Pass; Store is 4,552 bytes |
| Browser backup schema, integer limits and hostile label tests | Pass |
| Desktop and 390 px embedded viewport visual review | Pass; previews contain no household data |
| Native HA custom entities | Eight entities discovered |
| Original power/up/down saved indicators | Preserved after builder upgrade |
| Custom JSON storage/reboot/error-path test | Pass: roundtrip, invalid import rejected, learn/cancel preserves capture, fixture survived OTA reboot and was cleaned |
| Physical original power replay | Confirmed by project owner before this release |
| New custom remote physical learn/send | Requires owner test with a compatible remote |
| Speed-up/down and fan estimate accuracy | Requires physical verification |
| Long-term Wi-Fi reliability | Not established; weak signal observed during OTA |
| Printed enclosure fit and snap durability | Not physically verified |
| GitHub auto-update download/install | Not implemented; staged controls only |

The opt-in device smoke test creates only known synthetic data on an empty custom store. It never sends RF. Use stage, reboot/OTA, then verify-cleanup. It refuses cleanup if the fixture changed or other custom buttons appeared. Original captures are never exported or overwritten by this test.

During testing, URL-encoded layouts exceeded ESPHome's form limit. The backend now receives bounded raw JSON chunks. ESPHome's IDF adapter also mapped unsupported HTTP 202 to 500; the API now acknowledges with 200 and clients still wait for a changed revision and inspect errors before reporting success.

Custom NVS data and the HTTP/main-loop access path are protected separately from legacy preference storage. Saved custom commands survive a discarded relearn. Synthetic tests cannot prove that an appliance responds to a new waveform.

Deployment builds contain private credentials and are excluded from public source/release archives. The public workflow uses example credentials and does not publish flashable binaries.

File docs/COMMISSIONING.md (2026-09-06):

# First hardware test

## What is known

The target fan is the Vornado Airbar 4; the manufacturer describes an RF remote. The hardware consists of an ESP32-C3 Super Mini and a CC1101/SMA 433 MHz module.

## What is still unknown

Power replay has been confirmed by the project owner using the current ASK/OOK profile at 433.937 MHz. This does not establish compatibility with every revision or other remotes. Speed behavior and custom-remote appliance playback still require physical testing. A different modulation, rolling code, full-state protocol, or longer frame would require adapting the software.

## Capture procedure

1. Check wiring and confirm startup logs show a healthy CC1101, not an SPI identification failure.
2. Put the original remote roughly 0.5–1 m from the antenna. Start without transmitting from the bridge.
3. Open ESPHome logs. Press Learn power, then briefly press the remote power button once.
4. A structurally valid frame becomes a candidate. This check rejects malformed timing data; it does not identify the sender. Save only when capture coincides with your button press.
5. Repeat the capture several times and compare raw logs before trusting a frame. Cancel unexpected candidates.
6. Save one candidate for each command. Confirm the command-saved indicator becomes active. Wait 65 seconds, reboot, and confirm all three indicators remain active.
7. Test one button at a time. Explicit send requests enable transmission automatically. Watch the actual fan.
8. Current playback uses eight repeats, with no added gap because the saved frame already includes trailing silence. If one press causes multiple changes, measure the original sequence before changing repeats or timing.
9. Test the original remote afterward. Record which fan and remote revisions were tested.

The bridge sends no RF command at startup. Starting a learning window disables transmission. New capture attempts replace only the temporary candidate; a saved command remains until explicitly overwritten by Save capture.

## Capture boundaries

Frames must start with a positive mark, alternate sign, contain 16–512 timings, use individual durations of 50–30,000 microseconds, and total 3–500 ms. Receive idle time is 12 ms. A longer silence ends a capture; multi-frame protocols may need a different idle threshold. Do not stretch timing limits without checking the waveform and memory requirements.

## If nothing works

- If there are no plausible captures: verify GDO2 wiring and investigate frequency/modulation with a suitable RF capture tool.
- If captures appear without remote presses: those may be noise or another 433 MHz device.
- If repeated presses produce changing payloads: investigate addressing, counters, or rolling codes before replay.
- If the fan uses FSK: this OOK learning profile will need a measured FSK configuration or protocol implementation.
- If commands work but the displayed activity seems stale: Bridge activity reports bridge actions only, never fan telemetry.

Keep capture logs private by default; transmitter IDs may identify your remote. Record the successful settings and a sanitized trace before marking Airbar support verified.

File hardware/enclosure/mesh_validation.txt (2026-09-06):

BASE
  watertight: True
  winding_consistent: True
  is_volume: True
  body_count: 1
  triangles: 3524
  bounds_mm: [[0.0, 0.0, 0.0], [36.0, 43.5, 23.0]]
  extents_mm: [36.0, 43.5, 23.0]
  volume_mm3: 10511.44

LID
  watertight: True
  winding_consistent: True
  is_volume: True
  body_count: 1
  triangles: 3286
  bounds_mm: [[-1.0, 0.0, 0.0], [37.0, 43.5, 7.0]]
  extents_mm: [38.0, 43.5, 7.0]
  volume_mm3: 3341.23

ASSEMBLY FIT CHECKS
  base_to_lid_overlap_mm3: 0.000000
  base_to_cc1101_pcb_overlap_mm3: 0.000000
  lid_to_cc1101_pcb_overlap_mm3: 0.000000
  base_to_sma_barrel_overlap_mm3: 0.000000
  lid_to_sma_barrel_overlap_mm3: 0.000000
  base_to_esp32_pcb_overlap_mm3: 0.000000
  lid_to_esp32_pcb_overlap_mm3: 0.000000
  base_to_usb_c_shell_overlap_mm3: 0.000000
  lid_to_usb_c_shell_overlap_mm3: 0.000000

DESIGN CLEARANCES
  under_board_wiring_height_mm: 15.00
  lid_clearance_per_side_mm: 0.25
  snap_pocket_radial_clearance_mm: 0.18
  snap_arm_dimensions_mm: 8.0 wide x 5.0 free length x 1.0 thick
  cc1101_sma_radial_clearance_mm: 0.65
  usb_c_opening_mm: 12.0 x 6.4
  enclosure_fasteners: none (two flexible snap latches)
  board_fasteners: none (drop-on locating pins/guides)
  slicer_support_material_required: no

ALL_CHECKS_PASS: True

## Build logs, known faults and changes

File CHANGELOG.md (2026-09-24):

# Changelog

## 0.2.2-beta.1

- Preserve the Home Assistant fan estimate across Airbridge disconnects, device restarts, and Home Assistant restarts instead of forcing Unsynced.
- Add settings-page Off/Low/Medium/High state sync and show the Home Assistant estimate. Sync updates the estimate without transmitting RF and cancels pending fan-control sequences.
- Ignore reconnect snapshots and command-sequence gaps without clearing the saved estimate. State remains estimated; changes while offline may require manual sync.
- Include the deployed remote-observation support, receive diagnostics, and physical-BOOT-gated encryption-key reveal in the public source. Passive remote reception still requires hardware verification.

- Document the API-key finding aid for Home Assistant setup and reinforce that discovered keys must stay private.
- Clarify that the dedicated HomeKit bridge publishes the combined BZP Airbridge fan entity, not separate power/speed controls.
- Explain why the Home Assistant HomeKit service-device page can appear empty and how to recover a stale Apple Home pairing after a bridge reset.

## 0.2.0-beta.1

- Four custom remote layouts and eight stable custom button slots.
- Label/icon/order editing and individual learning with countdown, explicit save/discard.
- Private JSON backups, schema/pulse validation, separate versioned NVS storage.
- Existing Vornado global IDs and button names preserved.
- Explicit commands automatically enable transmission; learning blocks sending.
- Storage, pulse, and backup validation tests.
- Updated setup, integration, recovery, security, and branding documentation.

GitHub auto-update delivery is not implemented. RF compatibility and speed behavior still require testing with the target appliance.

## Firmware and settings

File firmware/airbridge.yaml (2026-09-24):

substitutions:
  name: bzp-airbridge
  friendly_name: BZP Airbridge
  # Initial tuning hypothesis from the earlier remote research. Verify by capture.
  rf_frequency: 433.937MHz

esphome:
  name: ${name}
  friendly_name: ${friendly_name}
  min_version: 2026.8.2
  includes:
    - pulse_store.h
    - remote_observer.h
    - reception_diagnostics.h
  on_boot:
    priority: -100
    then:
      - lambda: |-
          id(builder).set_tx_callback([](int slot) { id(send_command).execute(slot + 3); });
          id(builder).set_busy_callback([]() { return id(transmitting) || id(learn_target) >= 0 || id(candidate_target) >= 0; });
      - cc1101.begin_rx: radio
      - component.update: firmware_version
      - component.update: update_status
      - component.update: command_observed
      - text_sensor.template.publish:
          id: activity
          state: Ready

esp32:
  board: esp32-c3-devkitm-1
  framework:
    type: esp-idf

logger:
  level: DEBUG
  hardware_uart: USB_SERIAL_JTAG

api:
  encryption:
    key: !secret api_encryption_key

ota:
  - platform: esphome
    password: !secret ota_password

wifi:
  ssid: !secret wifi_ssid
  password: !secret wifi_password
  ap:
    ssid: BZP Airbridge Setup
    password: !secret fallback_password

captive_portal:

external_components:
  - source:
      type: local
      path: components
    components: [airbridge_network, cc1101, remote_builder]

airbridge_network:
  pairing_key: !secret api_encryption_key
  pairing_pin:
    number: GPIO9
    inverted: true
    mode: INPUT_PULLUP

remote_builder:
  id: builder

web_server:
  port: 80
  version: 2
  css_url: ""
  js_url: ""
  css_include: ui/settings.css
  js_include: ui/settings-bundle.js

# Persist only the three confirmed frames, at most once per minute.
preferences:
  flash_write_interval: 1min

spi:
  clk_pin: GPIO4
  miso_pin: GPIO5
  mosi_pin: GPIO6

cc1101:
  id: radio
  cs_pin: GPIO7
  frequency: ${rf_frequency}
  modulation_type: ASK/OOK
  # Raw remote pulses have no CC1101 packet preamble/sync word.
  sync_mode: None
  # TI DN022 OOK starting point: AGCCTRL2/1/0 = 03/00/91.
  magn_target: 33dB
  max_dvga_gain: Default
  wait_time: "16"
  filter_length_ask_ook: 8dB
  foc_limit: Disabled
  filter_bandwidth: 203kHz
  symbol_rate: 5000
  output_power: 0

globals:
  - id: scan_step
    type: int
    initial_value: '0'
  - id: observed_sequence
    type: uint32_t
    initial_value: '0'
  - id: sending_slot
    type: int
    initial_value: '-1'
  - id: power_frame
    type: std::array<int32_t, 513>
    restore_value: true
    initial_value: 'std::array<int32_t, 513>{}'
  - id: up_frame
    type: std::array<int32_t, 513>
    restore_value: true
    initial_value: 'std::array<int32_t, 513>{}'
  - id: down_frame
    type: std::array<int32_t, 513>
    restore_value: true
    initial_value: 'std::array<int32_t, 513>{}'
  - id: candidate
    type: std::array<int32_t, 513>
    initial_value: 'std::array<int32_t, 513>{}'
  - id: learn_target
    type: int
    initial_value: '-1'
  - id: candidate_target
    type: int
    initial_value: '-1'
  - id: transmitting
    type: bool
    initial_value: 'false'

remote_receiver:
  id: rf_rx
  pin: GPIO3
  filter: 50us
  idle: 12ms
  buffer_size: 8kb
  # Keep background RF noise out of logs; learning still receives raw frames.
  on_raw:
    then:
      - lambda: |-
          airbridge::rxcheck().receive(x);
          if (!id(transmitting) && id(builder).learning()) { id(builder).capture(x); return; }
          if (id(transmitting) || !airbridge::valid(x)) return;
          if (id(learn_target) < 0) {
            if (id(candidate_target) >= 0 || id(builder).capture_pending()) return;
            int slot = airbridge::observer().receive(x, id(power_frame), id(up_frame), id(down_frame), millis());
            if (slot >= 0) {
              id(command_observed).publish_state(std::to_string(++id(observed_sequence)) + ":rx:" + std::to_string(slot));
              ESP_LOGI("airbridge", "Physical remote command recognized: %d", slot);
            }
            return;
          }
          id(candidate) = airbridge::pack(x);
          id(candidate_target) = id(learn_target);
          id(learn_target) = -1;
          id(learn_timeout).stop();
          id(activity).publish_state("Candidate received - press Save capture");
          ESP_LOGI("airbridge", "Candidate: %u pulses; awaiting explicit save", unsigned(x.size()));
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

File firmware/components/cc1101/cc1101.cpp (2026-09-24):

#include "cc1101.h"
#include "cc1101pa.h"
#include "esphome/core/helpers.h"
#include "esphome/core/log.h"
#include <cmath>

namespace esphome::cc1101 {

static const char *const TAG = "cc1101";

static void split_float(float value, int mbits, uint8_t &e, uint32_t &m) {
  int e_tmp;
  float m_tmp = std::frexp(value, &e_tmp);
  if (e_tmp <= mbits) {
    e = 0;
    m = 0;
    return;
  }
  e = static_cast<uint8_t>(e_tmp - mbits - 1);
  m = static_cast<uint32_t>(((m_tmp * 2 - 1) * (1 << (mbits + 1))) + 1) >> 1;
  if (m == (1UL << mbits)) {
    e = e + 1;
    m = 0;
  }
}

CC1101Component::CC1101Component() {
  // Datasheet defaults
  memset(&this->state_, 0, sizeof(this->state_));
  this->state_.GDO2_CFG = 0x0D;  // Serial Data (for RX on GDO2)
  this->state_.GDO1_CFG = 0x2E;
  this->state_.GDO0_CFG = 0x0D;  // Serial Data (for RX on GDO0 / TX Input)
  this->state_.FIFO_THR = 7;
  this->state_.SYNC1 = 0xD3;
  this->state_.SYNC0 = 0x91;
  this->state_.PKTLEN = 0xFF;
  this->state_.APPEND_STATUS = 1;
  this->state_.LENGTH_CONFIG = 1;
  this->state_.CRC_EN = 1;
  this->state_.WHITE_DATA = 1;
  this->state_.FREQ_IF = 0x0F;
  this->state_.FREQ2 = 0x1E;
  this->state_.FREQ1 = 0xC4;
  this->state_.FREQ0 = 0xEC;
  this->state_.DRATE_E = 0x0C;
  this->state_.CHANBW_E = 0x02;
  this->state_.DRATE_M = 0x22;
  this->state_.SYNC_MODE = 2;
  this->state_.CHANSPC_E = 2;
  this->state_.NUM_PREAMBLE = 2;
  this->state_.CHANSPC_M = 0xF8;
  this->state_.DEVIATION_M = 7;
  this->state_.DEVIATION_E = 4;
  this->state_.RX_TIME = 7;
  this->state_.CCA_MODE = 3;
  this->state_.PO_TIMEOUT = 1;
  this->state_.FOC_LIMIT = 2;
  this->state_.FOC_POST_K = 1;
  this->state_.FOC_PRE_K = 2;
  this->state_.FOC_BS_CS_GATE = 1;
  this->state_.BS_POST_KP = 1;
  this->state_.BS_POST_KI = 1;
  this->state_.BS_PRE_KP = 2;
  this->state_.BS_PRE_KI = 1;
  this->state_.MAGN_TARGET = 3;
  this->state_.AGC_LNA_PRIORITY = 1;
  this->state_.FILTER_LENGTH = 1;
  this->state_.WAIT_TIME = 1;
  this->state_.HYST_LEVEL = 2;
  this->state_.WOREVT1 = 0x87;
  this->state_.WOREVT0 = 0x6B;
  this->state_.RC_CAL = 1;
  this->state_.EVENT1 = 7;
  this->state_.RC_PD = 1;
  this->state_.MIX_CURRENT = 2;
  this->state_.LODIV_BUF_CURRENT_RX = 1;
  this->state_.LNA2MIX_CURRENT = 1;
  this->state_.LNA_CURRENT = 1;
  this->state_.LODIV_BUF_CURRENT_TX = 1;
  this->state_.FSCAL3_LO = 9;
  this->state_.CHP_CURR_CAL_EN = 2;
  this->state_.FSCAL3_HI = 2;
  this->state_.FSCAL2 = 0x0A;
  this->state_.FSCAL1 = 0x20;
  this->state_.FSCAL0 = 0x0D;
  this->state_.RCCTRL1 = 0x41;
  this->state_.FSTEST = 0x59;
  this->state_.PTEST = 0x7F;
  this->state_.AGCTEST = 0x3F;
  this->state_.TEST2 = 0x88;
  this->state_.TEST1 = 0x31;
  this->state_.TEST0_LO = 1;
  this->state_.VCO_SEL_CAL_EN = 1;
  this->state_.TEST0_HI = 2;

  // PKTCTRL0
  this->state_.PKT_FORMAT = 3;
  this->state_.LENGTH_CONFIG = 2;
  this->state_.FS_AUTOCAL = 1;

  // CRITICAL: Initialize PA Table to avoid transmitting 0 power (Silence)
  memset(this->pa_table_, 0, sizeof(this->pa_table_));
}

void IRAM_ATTR CC1101Component::gpio_intr(CC1101Component *arg) { arg->enable_loop_soon_any_context(); }

void CC1101Component::setup() {
  this->spi_setup();

  if (this->gdo0_pin_ != nullptr) {
    this->gdo0_pin_->setup();
  }

  this->configure();
  if (this->is_failed()) {
    return;
  }

  // Defer pin mode setup until after all components have completed setup()
  // This handles the case where remote_transmitter runs after CC1101 and changes pin mode
  if (this->gdo0_pin_ != nullptr) {
    this->defer([this]() {
      this->gdo0_pin_->pin_mode(gpio::FLAG_INPUT);
      if (this->state_.PKT_FORMAT == static_cast<uint8_t>(PacketFormat::PACKET_FORMAT_FIFO)) {
        this->gdo0_pin_->attach_interrupt(&CC1101Component::gpio_intr, this, gpio::INTERRUPT_RISING_EDGE);
      }
    });
  }
}

void CC1101Component::configure() {
  // Manual reset sequence per CC1101 datasheet section 19.1.2
  this->cs_->digital_write(true);
  delayMicroseconds(1);
  this->cs_->digital_write(false);
  delayMicroseconds(1);
  this->cs_->digital_write(true);
  delayMicroseconds(41);
  this->cs_->digital_write(false);
  delay(5);

  this->strobe_(Command::RES);
  delay(5);

  this->read_(Register::PARTNUM);
  this->read_(Register::VERSION);
  this->chip_id_ = encode_uint16(this->state_.PARTNUM, this->state_.VERSION);
  ESP_LOGD(TAG, "CC1101 found! Chip ID: 0x%04X", this->chip_id_);
  if (this->state_.VERSION == 0 || this->state_.PARTNUM == 0xFF) {
    ESP_LOGE(TAG, "Failed to verify CC1101.");
    this->mark_failed();
    return;
  }

  this->initialized_ = true;

  for (uint8_t i = 0; i <= static_cast<uint8_t>(Register::TEST0); i++) {
    if (i == static_cast<uint8_t>(Register::FSTEST) || i == static_cast<uint8_t>(Register::AGCTEST)) {
      continue;
    }
    this->write_(static_cast<Register>(i));
  }
  this->set_output_power(this->output_power_requested_);

  if (!this->enter_rx_()) {
    this->mark_failed();
    return;
  }
}

void CC1101Component::call_listeners_(const std::vector<uint8_t> &packet, float freq_offset, float rssi, uint8_t lqi) {
  for (auto &listener : this->listeners_) {
    listener->on_packet(packet, freq_offset, rssi, lqi);
  }
  this->packet_trigger_.trigger(packet, freq_offset, rssi, lqi);
}
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

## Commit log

2026-09-06 Introduce BZP Airbridge Remote Builder beta
    [vornado_rf_enclosure_base.stl, vornado_rf_enclosure_lid.stl]
2026-09-06 Add owner-supplied case base and top without geometry changes
    [Vornado Fan Controller Case Top.stl, Vornado Fan Controller Case.stl]
2026-09-06 Link MakerWorld case and print profile
2026-09-24 Restore fan state after reconnect and add settings state sync
